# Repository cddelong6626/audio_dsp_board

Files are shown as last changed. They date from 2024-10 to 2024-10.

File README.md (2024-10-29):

# audio_dsp_board

This board will take in audio input from either USB-C (2.0) or an audio jack and output processed audio through a separate audio jack. 

Stereo ADC/DAC provided by SGTL5000 audio codec. Data processing performed by STM32F405 microcontroller.

Image of board with 3D models from KiCad:


Image of board with 3D models from JLCPCB:


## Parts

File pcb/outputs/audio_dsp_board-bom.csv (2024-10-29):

Reference | Value | Datasheet | Footprint | Qty | DNP | "LCSC Part Number"
C1,C3,C5,C6,C9,C17,C30 | 100n | ~ | Capacitor_SMD:C_0402_1005Metric | 7 | C1581
C2,C10,C26,C28 | 10u | ~ | Capacitor_SMD:C_0603_1608Metric | 4 | C15499
C4,C7 | 10p | ~ | Capacitor_SMD:C_0402_1005Metric | 2 | C32949
C8,C16 | 2.2u | ~ | Capacitor_SMD:C_0402_1005Metric | 2 | C12530
C11,C27,C29 | 22u | ~ | Capacitor_SMD:C_0805_2012Metric | 3 | C5674
C12,C13,C20,C21,C22 | 0.1u | ~ | Capacitor_SMD:C_0402_1005Metric | 5 | C141382
C14,C15 | 220u | ~ | Capacitor_Tantalum_SMD:CP_EIA-3528-12_Kemet-T | 2 | C7200
C18,C19,C23,C25 | 1u | ~ | Capacitor_SMD:C_0402_1005Metric | 4 | C14445
C24 | 10n | ~ | Capacitor_SMD:C_0402_1005Metric | 1 | C1524
D1,D2,D3 | LED | ~ | Diode_SMD:D_0603_1608Metric | 3 | C20785
FB1 | FerriteBead | ~ | Diode_SMD:D_0603_1608Metric | 1 | C1002
J1,J2 | AudioJack4 | ~ | Connector_Audio:Jack_3.5mm_PJ320D_Horizontal | 2 | C431535
J3 | Conn_01x04_Pin | ~ | Connector_PinHeader_2.54mm:PinHeader_1x04_P2.54mm_Vertical | 1 | C2905435
J4 | USB_C_Receptacle_USB2.0_14P | https://www.usb.org/sites/default/files/documents/usb_type-c.zip | Connector_USB:USB_C_Receptacle_XKB_U262-16XN-4BVC11 | 1 | C319148
R1,R2,R8 | 10k | ~ | Resistor_SMD:R_0402_1005Metric | 3 | C60490
R3 | 2.2k | ~ | Resistor_SMD:R_0402_1005Metric | 1 | C102890
R4,R5 | 5.1k | ~ | Resistor_SMD:R_0402_1005Metric | 2 | C103079
R6,R7 | 4.7k | ~ | Resistor_SMD:R_0402_1005Metric | 2 | C25900
R9,R10,R11 | 1k5 | ~ | Resistor_SMD:R_0402_1005Metric | 3 | C25867
RV1 | R_Potentiometer | ~ | AAA:TRIM_3362P-1-103LF | 1 | C58159
RESET | SW_Push | ~ | AAA:EL23520JLFS | 1 | C36364017
SW2,SW3 | SW_SPDT | ~ | Button_Switch_SMD:SW_SPDT_PCM12 | 2 | C221841
U1 | STM32F405RGTx | https://www.st.com/resource/en/datasheet/stm32f405rg.pdf | Package_QFP:LQFP-64_10x10mm_P0.5mm | 1 | C15742
U2 | SGTL5000XNLA3 | https://www.nxp.com/docs/en/data-sheet/SGTL5000.pdf | Package_DFN_QFN:QFN-20-1EP_3x3mm_P0.4mm_EP1.65x1.65mm | 1 | C2802658
U3,U4 | AMS1117-3.3 | http://www.advanced-monolithic.com/pdf/ds1117.pdf | Package_TO_SOT_SMD:SOT-223-3_TabPin2 | 2 | C6186
U5 | AMS1117-1.5 | http://www.advanced-monolithic.com/pdf/ds1117.pdf | Package_TO_SOT_SMD:SOT-223-3_TabPin2 | 1 | C16172
Y1 | 16MHz | https://www.lcsc.com/datasheet/lcsc_datasheet_2409301532_YXC-Crystal-Oscillators-X322516MMB4SI_C112972.pdf | Crystal:Crystal_SMD_3225-4Pin_3.2x2.5mm | 1 | C12668

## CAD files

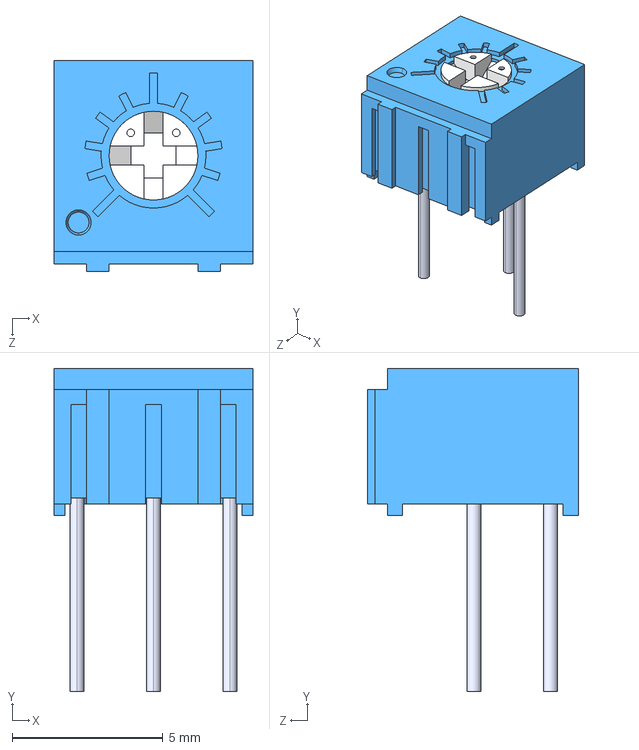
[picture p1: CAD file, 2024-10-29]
pcb/audio_dsp_board/cad_files/3362P_1_103LF/3362P-1-103LF.step
6.60 x 10.7 x 6.99 mm

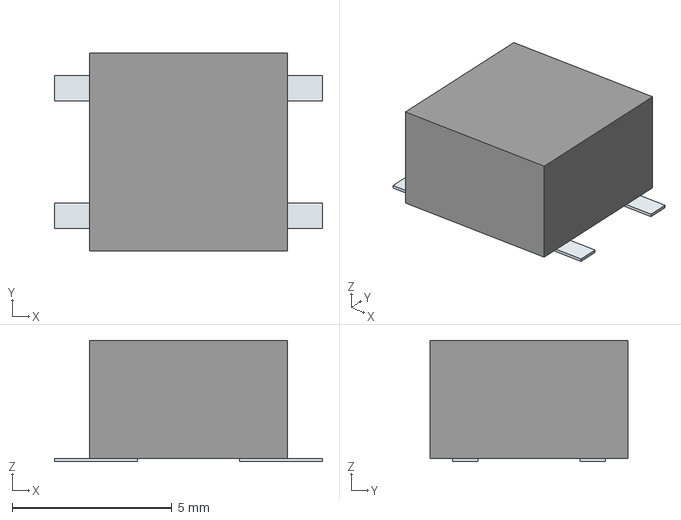
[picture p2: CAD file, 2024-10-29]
pcb/audio_dsp_board/cad_files/EL2-35-20J-LFS/EL2_35_20J_LFS.stp
8.40 x 6.20 x 3.80 mm
Pins

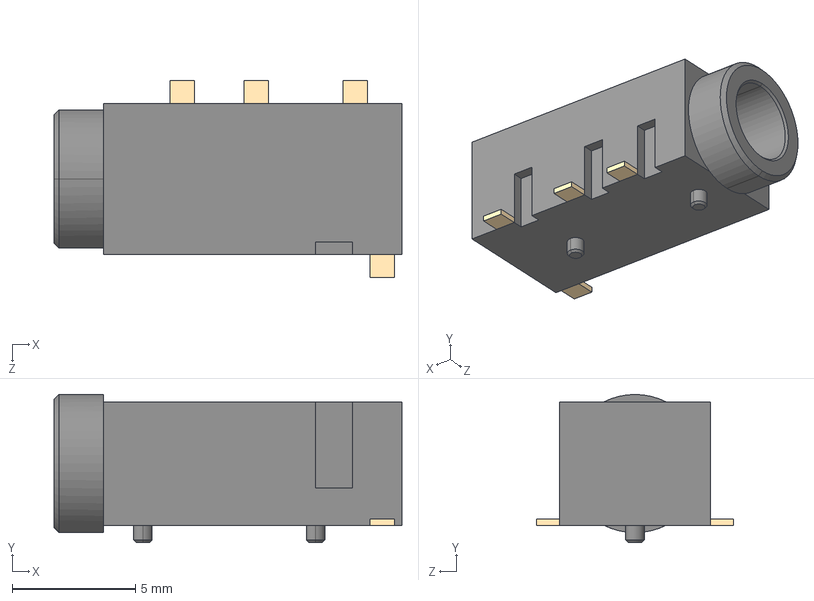
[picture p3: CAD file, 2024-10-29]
pcb/audio_dsp_board/cad_files/PJ-320D-A--3DModel-STEP-56544.STEP
14.1 x 6.00 x 8.00 mm

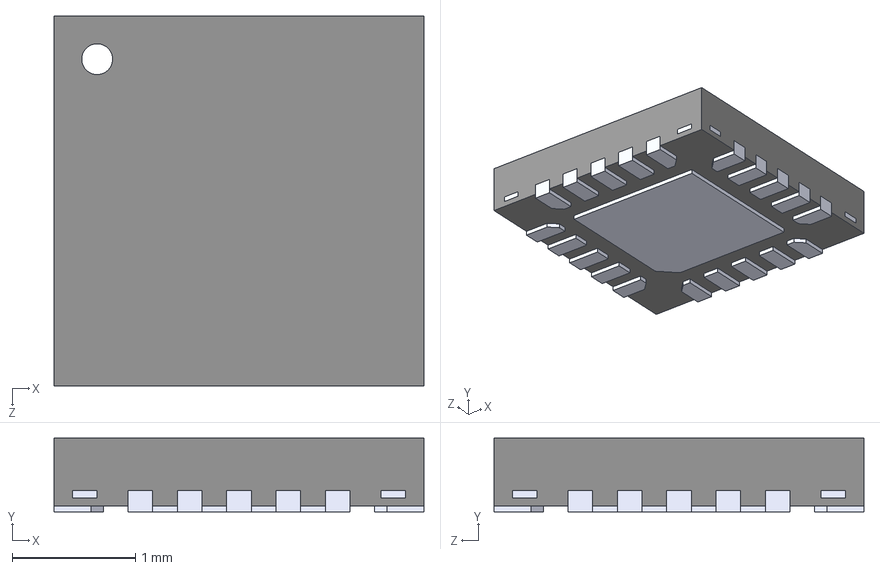
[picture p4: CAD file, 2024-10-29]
pcb/audio_dsp_board/cad_files/SGTL5000XNLA3.STEP
3.00 x 0.6 x 3.00 mm

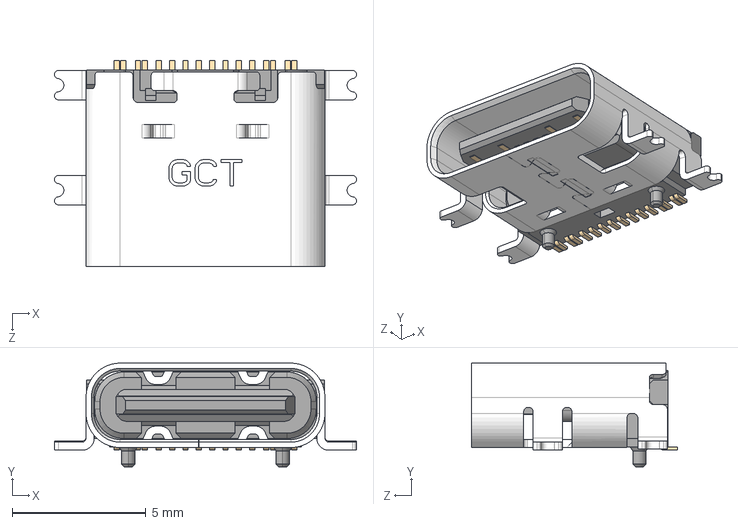
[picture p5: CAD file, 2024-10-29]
pcb/audio_dsp_board/cad_files/USB4110GFA.step
11.3 x 3.89 x 7.70 mm

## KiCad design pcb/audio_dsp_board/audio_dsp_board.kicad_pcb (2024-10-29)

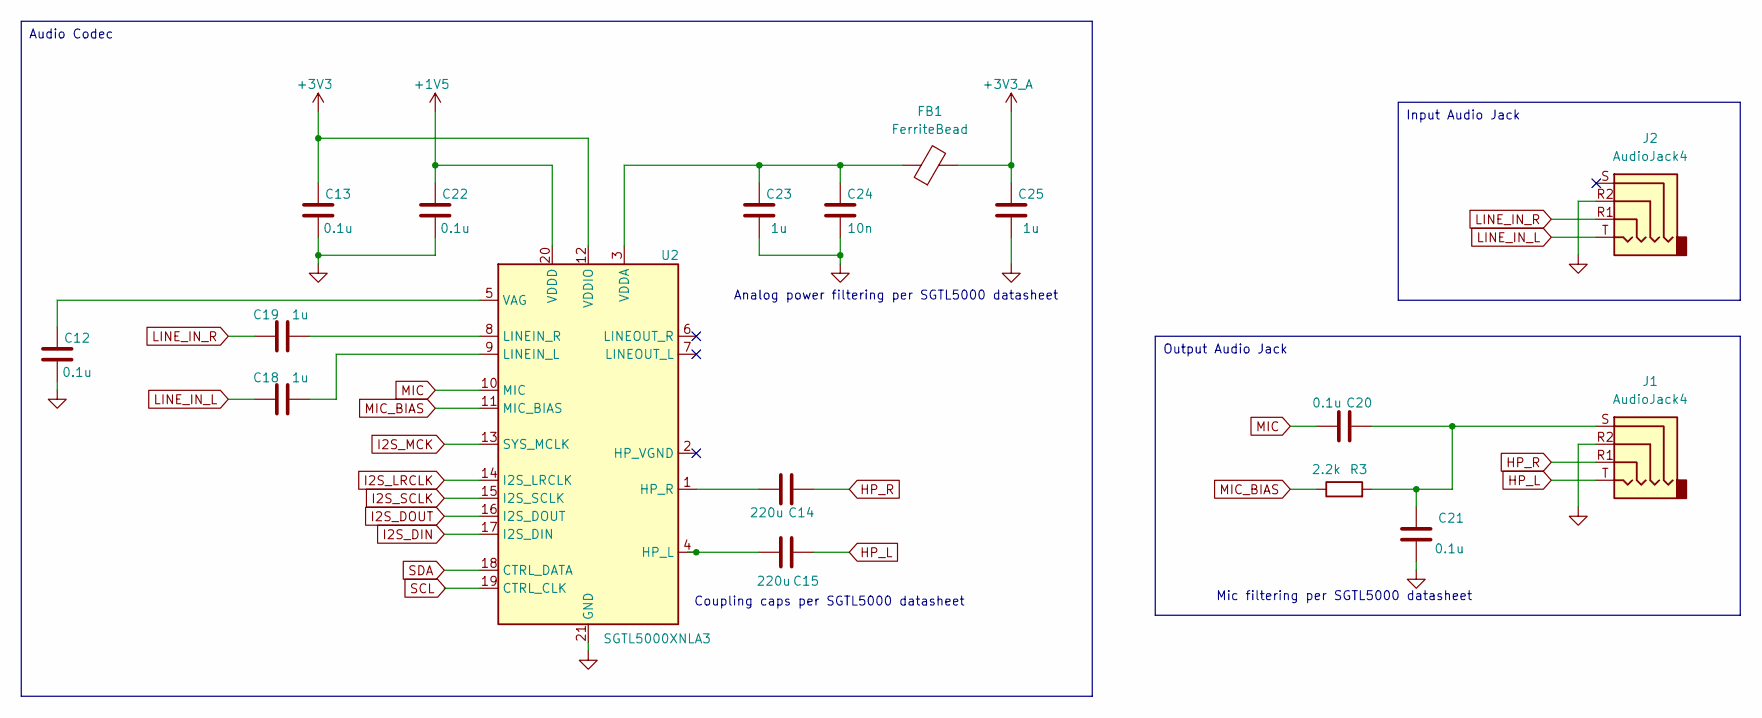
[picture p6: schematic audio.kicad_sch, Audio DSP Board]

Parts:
C12, C13, C20, C21, C22: 0.1u; C_0402_1005Metric
C14, C15: 220u; CP_EIA-3528-12_Kemet-T
C18, C19, C23, C25: 1u; C_0402_1005Metric
C24: 10n; C_0402_1005Metric
FB1: FerriteBead; D_0603_1608Metric
J1, J2: AudioJack4; Jack_3.5mm_PJ320D_Horizontal
R3: 2.2k; R_0402_1005Metric
U2: SGTL5000XNLA3; QFN-20-1EP_3x3mm_P0.4mm_EP1.65x1.65mm

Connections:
+1V5: C22.1, U2.20 (VDDD); also elsewhere on the board
+3V3: C13.1, U2.12 (VDDIO); also elsewhere on the board
+3V3_A: C25.1, FB1.2; also elsewhere on the board
GND: C12.2, C13.2, C21.2, C22.2, C23.2, C24.2, C25.2, J1.R2, J2.R2, U2.21 (GND); also elsewhere on the board
HP_L: C15.1, J1.T
HP_R: C14.1, J1.R1
I2S_DIN: U2.17 (I2S_DIN); also elsewhere on the board
I2S_DOUT: U2.16 (I2S_DOUT); also elsewhere on the board
I2S_LRCLK: U2.14 (I2S_LRCLK); also elsewhere on the board
I2S_MCK: U2.13 (SYS_MCLK); also elsewhere on the board
I2S_SCLK: U2.15 (I2S_SCLK); also elsewhere on the board
LINE_IN_L: C18.1, J2.T
LINE_IN_R: C19.1, J2.R1
MIC: C20.2, U2.10 (MIC)
MIC_BIAS: R3.1, U2.11 (MIC_BIAS)
unnamed: C20.1, C21.1, J1.S, R3.2
unnamed: C15.2, U2.4 (HP_L)
unnamed: C14.2, U2.1 (HP_R)
unnamed: C18.2, U2.9 (LINEIN_L)
unnamed: C19.2, U2.8 (LINEIN_R)
unnamed: C12.1, U2.5 (VAG)
unnamed: C23.1, C24.1, FB1.1, U2.3 (VDDA)
SCL: U2.19 (CTRL_CLK); also elsewhere on the board
SDA: U2.18 (CTRL_DATA); also elsewhere on the board

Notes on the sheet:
Audio Codec
Output Audio Jack
Input Audio Jack
Analog power filtering per SGTL5000 datasheet
Mic filtering per SGTL5000 datasheet
Coupling caps per SGTL5000 datasheet

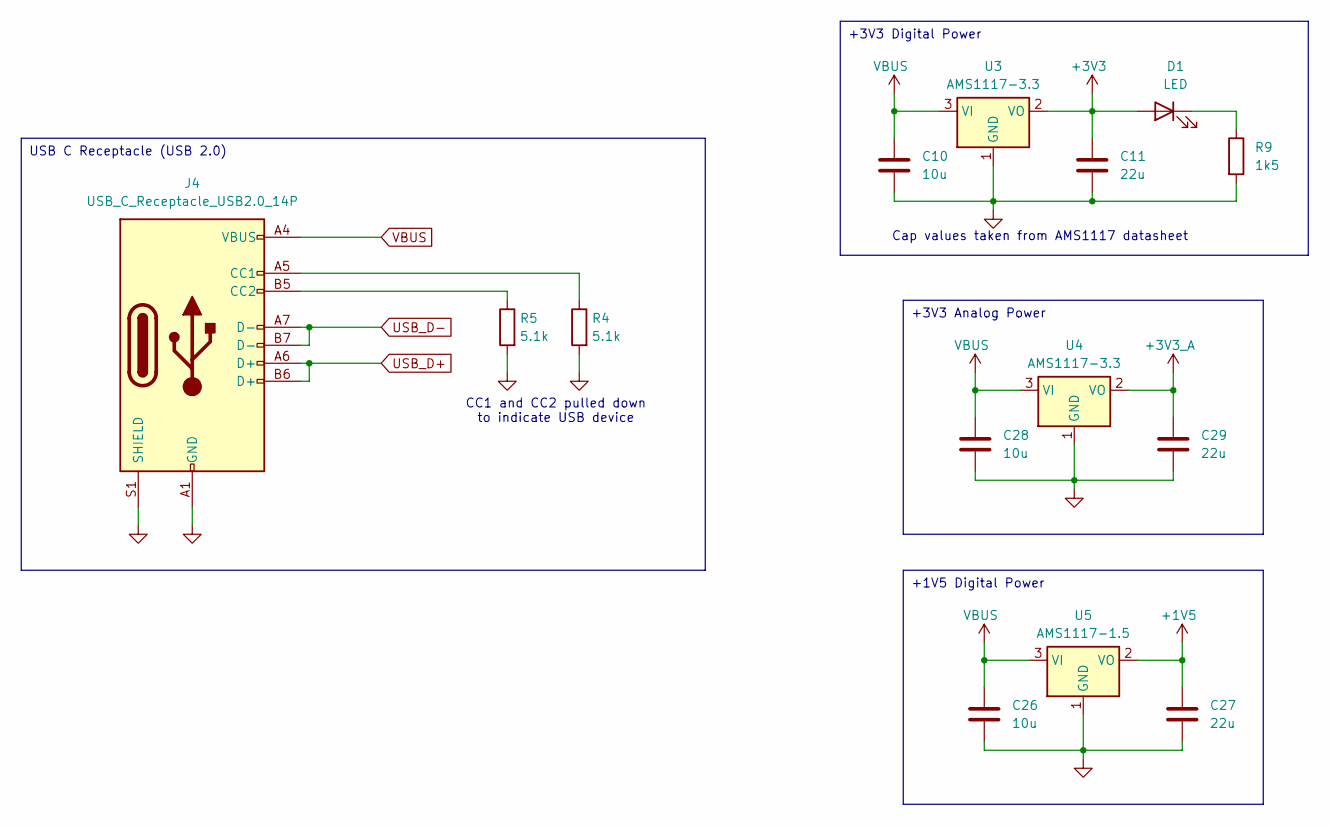
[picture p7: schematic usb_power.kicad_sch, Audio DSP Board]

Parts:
C10, C26, C28: 10u; C_0603_1608Metric
C11, C27, C29: 22u; C_0805_2012Metric
D1: LED; D_0603_1608Metric
J4: USB_C_Receptacle_USB2.0_14P; USB_C_Receptacle_XKB_U262-16XN-4BVC11
R4, R5: 5.1k; R_0402_1005Metric
R9: 1k5; R_0402_1005Metric
U3, U4: AMS1117-3.3; SOT-223-3_TabPin2
U5: AMS1117-1.5; SOT-223-3_TabPin2

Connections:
+1V5: C27.1, U5.2 (VO); also elsewhere on the board
+3V3: C11.1, D1.2 (A), U3.2 (VO); also elsewhere on the board
+3V3_A: C29.1, U4.2 (VO); also elsewhere on the board
GND: C10.2, C11.2, C26.2, C27.2, C28.2, C29.2, J4.A1 (GND), J4.A12 (GND), J4.B1 (GND), J4.B12 (GND), J4.S1 (SHIELD), R4.2, R5.2, R9.2, U3.1 (GND), U4.1 (GND), U5.1 (GND); also elsewhere on the board
unnamed: D1.1 (K), R9.1
unnamed: J4.A5 (CC1), R4.1
unnamed: J4.B5 (CC2), R5.1
USB_D+: J4.A6 (D+), J4.B6 (D+); also elsewhere on the board
USB_D-: J4.A7 (D-), J4.B7 (D-); also elsewhere on the board
VBUS: C10.1, C26.1, C28.1, J4.A4 (VBUS), J4.A9 (VBUS), J4.B4 (VBUS), J4.B9 (VBUS), U3.3 (VI), U4.3 (VI), U5.3 (VI)

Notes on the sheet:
+1V5 Digital Power
USB C Receptacle (USB 2.0)
+3V3 Analog Power
+3V3 Digital Power
Cap values taken from AMS1117 datasheet
CC1 and CC2 pulled down to indicate USB device

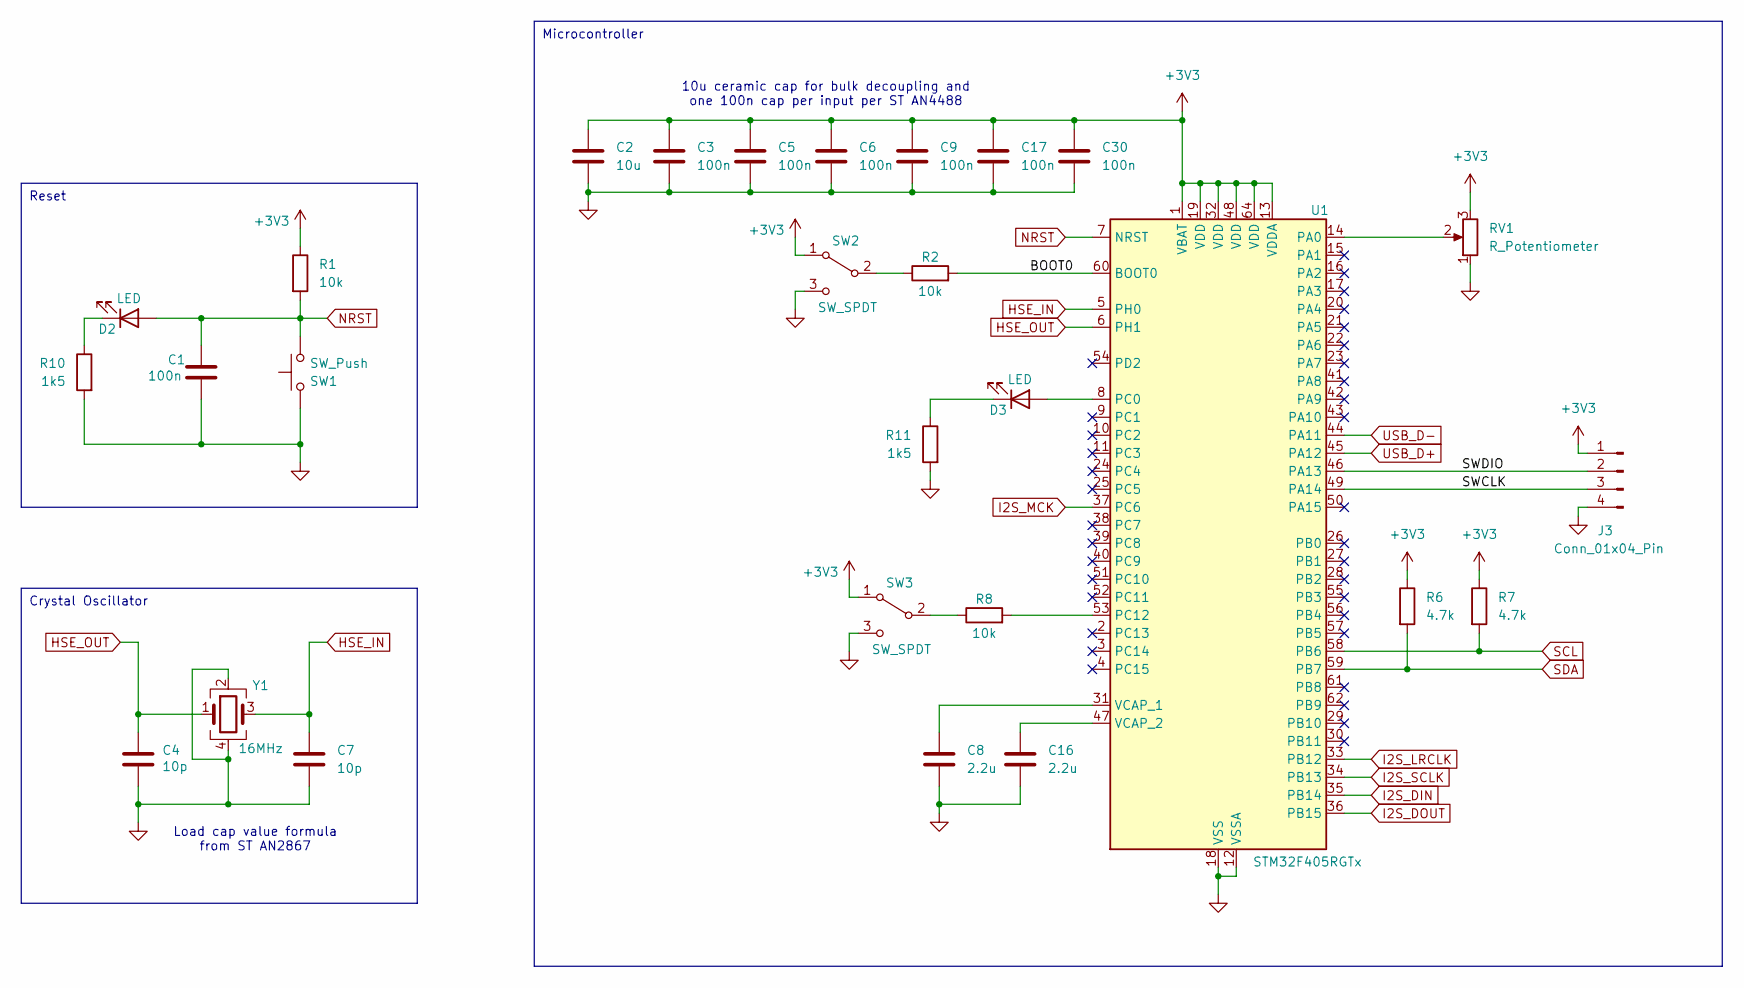
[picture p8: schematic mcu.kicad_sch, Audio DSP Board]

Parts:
C1, C3, C5, C6, C9, C17, C30: 100n; C_0402_1005Metric
C2: 10u; C_0603_1608Metric
C4, C7: 10p; C_0402_1005Metric
C8, C16: 2.2u; C_0402_1005Metric
D2, D3: LED; D_0603_1608Metric
J3: Conn_01x04_Pin; PinHeader_1x04_P2.54mm_Vertical
R1, R2, R8: 10k; R_0402_1005Metric
R6, R7: 4.7k; R_0402_1005Metric
R10, R11: 1k5; R_0402_1005Metric
RV1: R_Potentiometer; TRIM_3362P-1-103LF
SW1: SW_Push; EL23520JLFS
SW2, SW3: SW_SPDT; SW_SPDT_PCM12
U1: STM32F405RGTx; LQFP-64_10x10mm_P0.5mm
Y1: 16MHz; Crystal_SMD_3225-4Pin_3.2x2.5mm

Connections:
+3V3: C2.1, C3.1, C5.1, C6.1, C9.1, C17.1, C30.1, J3.1, R1.1, R6.1, R7.1, RV1.3, SW2.1 (A), SW3.1 (A), U1.1 (VBAT), U1.13 (VDDA), U1.19 (VDD), U1.32 (VDD), U1.48 (VDD), U1.64 (VDD); also elsewhere on the board
/MCU/BOOT0: R2.2, U1.60 (BOOT0)
/MCU/SWCLK: J3.3, U1.49 (PA14)
/MCU/SWDIO: J3.2, U1.46 (PA13)
GND: C1.2, C2.2, C3.2, C4.2, C5.2, C6.2, C7.2, C8.2, C9.2, C16.2, C17.2, C30.2, J3.4, R10.2, R11.2, RV1.1, SW1.2, SW2.3 (C), SW3.3 (C), U1.12 (VSSA), U1.18 (VSS), U1.63 (VSS), Y1.2, Y1.4; also elsewhere on the board
HSE_IN: C7.1, U1.5 (PH0), Y1.3
HSE_OUT: C4.1, U1.6 (PH1), Y1.1
I2S_DIN: U1.35 (PB14); also elsewhere on the board
I2S_DOUT: U1.36 (PB15); also elsewhere on the board
I2S_LRCLK: U1.33 (PB12); also elsewhere on the board
I2S_MCK: U1.37 (PC6); also elsewhere on the board
I2S_SCLK: U1.34 (PB13); also elsewhere on the board
NRST: C1.1, D2.2 (A), R1.2, SW1.1, U1.7 (NRST); also elsewhere on the board
unnamed: D2.1 (K), R10.1
unnamed: D3.2 (A), U1.8 (PC0)
unnamed: D3.1 (K), R11.1
unnamed: R2.1, SW2.2 (B)
unnamed: R8.1, SW3.2 (B)
unnamed: RV1.2, U1.14 (PA0)
unnamed: R8.2, U1.53 (PC12)
unnamed: C8.1, U1.31 (VCAP_1)
unnamed: C16.1, U1.47 (VCAP_2)
SCL: R7.2, U1.58 (PB6); also elsewhere on the board
SDA: R6.2, U1.59 (PB7); also elsewhere on the board
USB_D+: U1.45 (PA12); also elsewhere on the board
USB_D-: U1.44 (PA11); also elsewhere on the board

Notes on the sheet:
Crystal Oscillator
Microcontroller
Reset
Load cap value formula from ST AN2867
10u ceramic cap for bulk decoupling and one 100n cap per input per ST AN4488

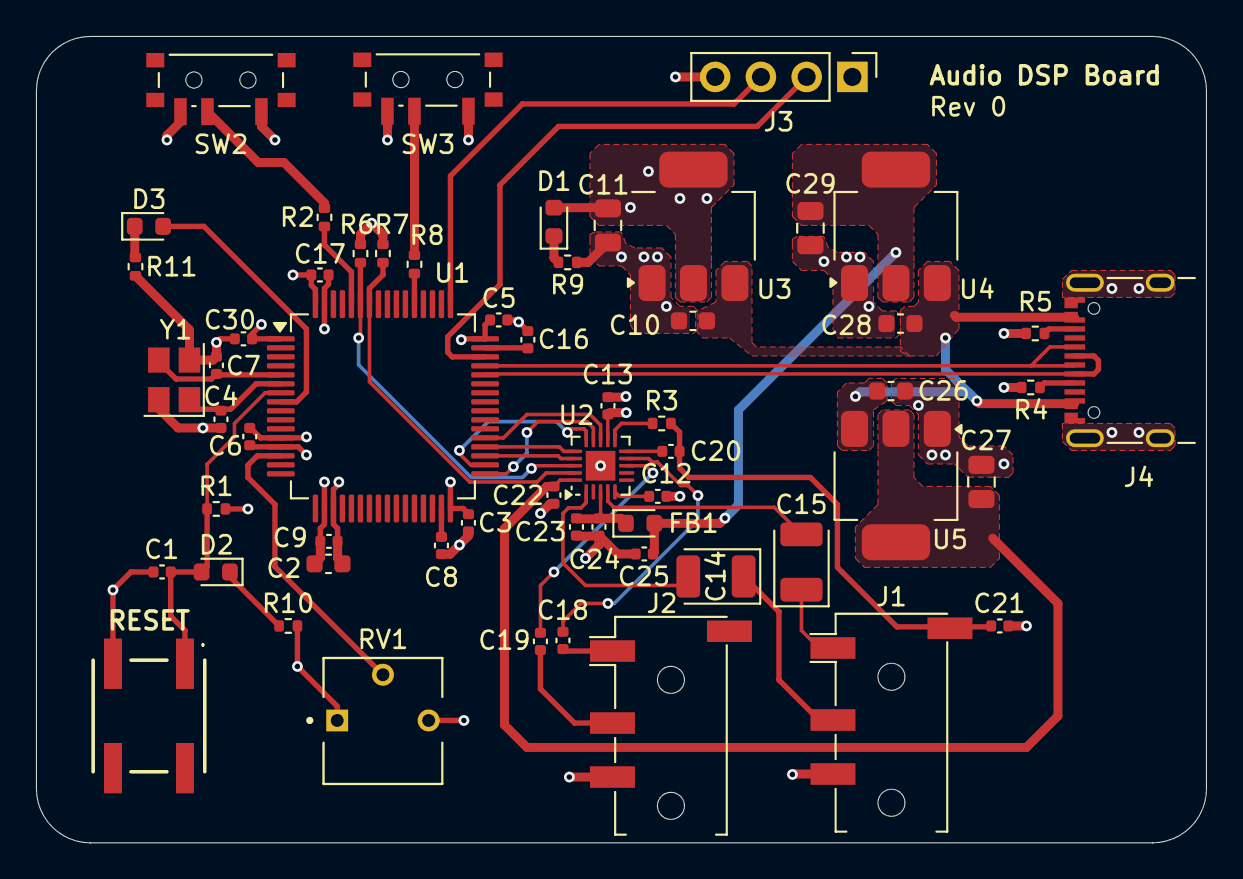
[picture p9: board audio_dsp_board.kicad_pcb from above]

Board: 4 copper layers, 65.0 x 44.8 mm, 59 parts (0 on the bottom side), 45 nets.

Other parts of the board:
RESET: SW_Push; EL23520JLFS

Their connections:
GND: RESET.2; also elsewhere on the board
NRST: RESET.1; also elsewhere on the board

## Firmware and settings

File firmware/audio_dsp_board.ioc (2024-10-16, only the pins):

Mcu.UserName=STM32F405RGTx
PA0-WKUP.Signal=ADCx_IN0
PA10.Signal=USB_OTG_FS_ID
PA11.Signal=USB_OTG_FS_DM
PA12.Signal=USB_OTG_FS_DP
PA13.Signal=SYS_JTMS-SWDIO
PA14.Signal=SYS_JTCK-SWCLK
PB12.Signal=I2S2_WS
PB13.Signal=I2S2_CK
PB14.Signal=I2S2_ext_SD
PB15.Signal=I2S2_SD
PB6.Signal=I2C1_SCL
PB7.Signal=I2C1_SDA
PC12.Signal=GPIO_Input
PC6.Signal=I2S2_MCK
PH0-OSC_IN.Signal=RCC_OSC_IN
PH1-OSC_OUT.Signal=RCC_OSC_OUT

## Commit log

2024-10-07 pcb files initial commit
    [audio_dsp_board.kicad_pcb, audio_dsp_board.kicad_sch]
2024-10-16 Rough draft of schematic capture done
    [audio.kicad_sch, audio_dsp_board.kicad_sch, mcu.kicad_sch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]
2024-10-29 Schematic capture, placement, routing complete
    Sending board to JLCPCB for manufacturing and assembly.
    [3362P-1-103LF.step, EL2_35_20J_LFS.stp, PJ-320D-A--3DModel-STEP-56544.STEP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]
